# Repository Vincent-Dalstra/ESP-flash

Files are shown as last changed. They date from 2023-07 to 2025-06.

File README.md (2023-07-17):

# ESP-flash
A USB to UART Serial interface implementing a CH340C.

Designed primarily to program board with embedded ESP32 modules. USB-micro and USB-c for minimum I-have-the-wrong-cable

For compatibility with other programmers, it follow the the ESPFlash 1x6 Header convention. https://github.com/SuperHouse/ESPFlash
Big thanks to them for developing it and putting it out there.

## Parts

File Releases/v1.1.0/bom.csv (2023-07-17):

Comment | Designator | Footprint | LCSC
C14663 | C103 | Capacitor_SMD:C_0603_1608Metric | C14663
CH340C | U103 | Package_SO:SOIC-16_3.9x9.9mm_P1.27mm | C84681
USB_B_Micro | J101 | Connector_USB_custom:USB_Micro-B_Amphenol_10118194_Horizontal | C132563
GREEN | D102,D103 | LED_SMD:LED_0603_1608Metric | C72043
0ZCK0050FF2E (TLC-PSMD050) | F101 | Fuse:Fuse_0805_2012Metric_Pad1.15x1.40mm_HandSolder | C261942
10kΩ | R105,R106 | Resistor_SMD:R_0603_1608Metric | C25804
10k | R103,R104 | Resistor_SMD:R_0805_2012Metric | C17414
10nF | C104 | Capacitor_SMD:C_0603_1608Metric | C14663
4.7uF/6V | C102 | Capacitor_SMD:C_0805_2012Metric | C1779
USB_C_Receptacle_USB2.0 | J102 | Connector_USB:USB_C_Receptacle_HRO_TYPE-C-31-M-12 | C165948
SW_SPDT | SW101 | Button_Switch_SMD:SW_SPDT_CK-JS102011SAQN | C125040
MMDT3904 | Q101 | Package_TO_SOT_SMD:SOT-363_SC-70-6 | C83572
5.1k | R101,R102 | Resistor_SMD:R_0603_1608Metric | C23186
ESD5Z3.3T1G | D101 | Diode_SMD:D_SOD-523 | C61148
1uF/10V | C101 | Capacitor_SMD:C_0805_2012Metric | C28323
TLV75533PDBV | U102 | Package_TO_SOT_SMD:SOT-23-5 | C2937042
ESD PROTECTION | U101 | Package_TO_SOT_SMD:SOT-23-6 | C294963

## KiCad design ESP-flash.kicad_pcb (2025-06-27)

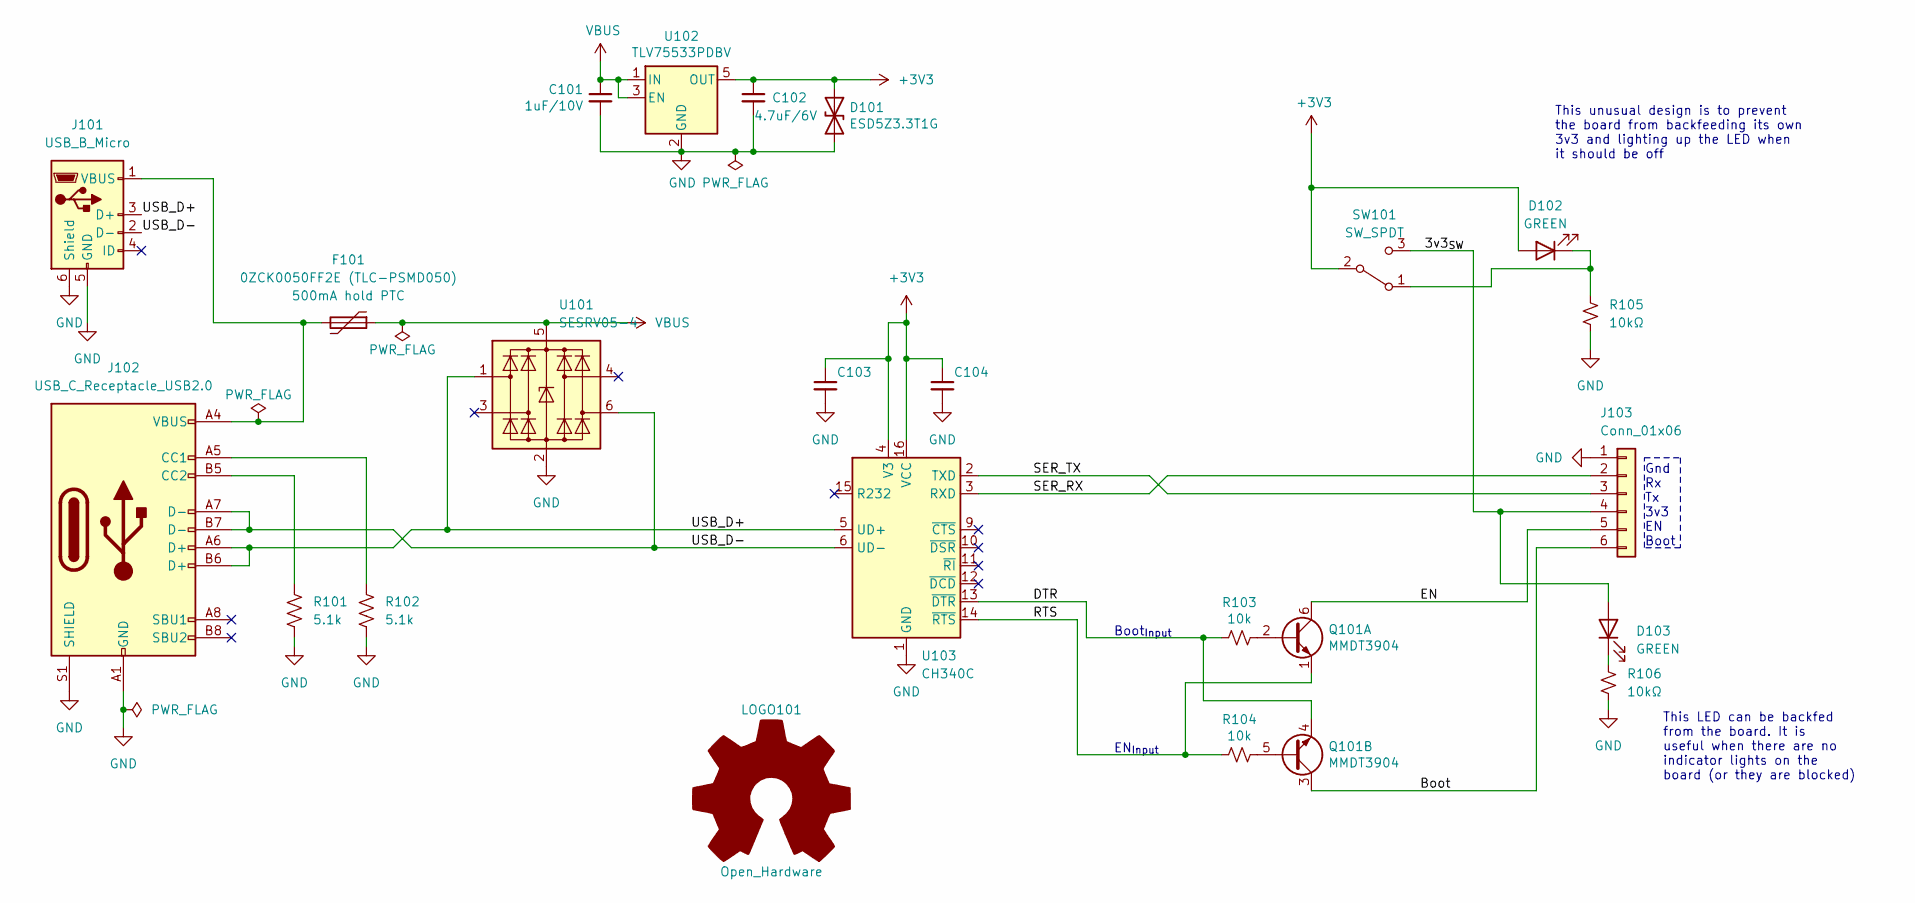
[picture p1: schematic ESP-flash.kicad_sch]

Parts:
C101: 1uF/10V; C_0805_2012Metric; LCSC C28323
C102: 4.7uF/6V; C_0805_2012Metric; LCSC C1779
C103: C14663; C_0603_1608Metric; LCSC C14663
C104: 10nF; C_0603_1608Metric; LCSC C14663
D101: ESD5Z3.3T1G; D_SOD-523; LCSC C61148
D102, D103: GREEN; LED_0603_1608Metric; LCSC C779453
F101: 0ZCK0050FF2E (TLC-PSMD050); Fuse_0805_2012Metric_Pad1.15x1.40mm_HandSolder; LCSC C516070
J101: USB_B_Micro; USB_Micro-B_Amphenol_10118194_Horizontal; LCSC C132563
J102: USB_C_Receptacle_USB2.0; USB_C_Receptacle_HRO_TYPE-C-31-M-12; LCSC C165948
J103: Conn_01x06; PinHeader_1x06_P2.54mm_Horizontal; LCSC C40877
LOGO101: Open_Hardware; OSHW-Logo2_7.3x6mm_SilkScreen
Q101: MMDT3904; SOT-363_SC-70-6; LCSC C83572
R101, R102: 5.1k; R_0603_1608Metric; LCSC C23186
R103, R104: 10k; R_0805_2012Metric; LCSC C17414
R105, R106: 10kΩ; R_0603_1608Metric; LCSC C25804
SW101: SW_SPDT; SW_SPDT_PCM12; LCSC C221841
U101: SESRV05-4; SOT-23-6; LCSC C294963
U102: TLV75533PDBV; SOT-23-5; LCSC C2937042
U103: CH340C; SOIC-16_3.9x9.9mm_P1.27mm; LCSC C84681

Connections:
+3V3: C102.1, C103.1, C104.1, D101.1 (A1), D102.2 (A), SW101.2 (B), U102.5 (OUT), U103.4 (V3), U103.16 (VCC)
/3v3_{SW}: D103.2 (A), J103.4, SW101.3 (C)
/Boot: J103.6, Q101.3 (C2)
/DTR: Q101.4 (E2), R103.2, U103.13 (~DTR)
/EN: J103.5, Q101.6 (C1)
/RTS: Q101.1 (E1), R104.2, U103.14 (~RTS)
/SER_RX: J103.2, U103.3 (RXD)
/SER_TX: J103.3, U103.2 (TXD)
/USB_D+: J101.3 (D+), J102.A6 (D+), J102.B6 (D+), U101.1 (I/O1), U103.5 (UD+)
/USB_D-: J101.2 (D-), J102.A7 (D-), J102.B7 (D-), U101.6 (I/O4), U103.6 (UD-)
GND: C101.2, C102.2, C103.2, C104.2, D101.2 (A2), J101.5 (GND), J101.6 (Shield), J102.A1 (GND), J102.A12 (GND), J102.B1 (GND), J102.B12 (GND), J102.S1 (SHIELD), J103.1, R101.1, R102.1, R105.2, R106.2, U101.2 (GND), U102.2 (GND), U103.1 (GND)
unnamed: D102.1 (K), R105.1, SW101.1 (A)
unnamed: D103.1 (K), R106.1
unnamed: F101.2, J101.1 (VBUS), J102.A4 (VBUS), J102.A9 (VBUS), J102.B4 (VBUS), J102.B9 (VBUS)
unnamed: J102.A5 (CC1), R102.2
unnamed: J102.B5 (CC2), R101.2
unnamed: Q101.2 (B1), R103.1
unnamed: Q101.5 (B2), R104.1
VBUS: C101.1, F101.1, U101.5 (VBUS), U102.1 (IN), U102.3 (EN)

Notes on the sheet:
Gnd Rx Tx 3v3 EN Boot
Boot_{Input}
EN_{Input}
This unusual design is to prevent the board from backfeeding its own 3v3 and lighting up the LED when it should be off
This LED can be backfed from the board. It is useful when there are no indicator lights on the board (or they are blocked)

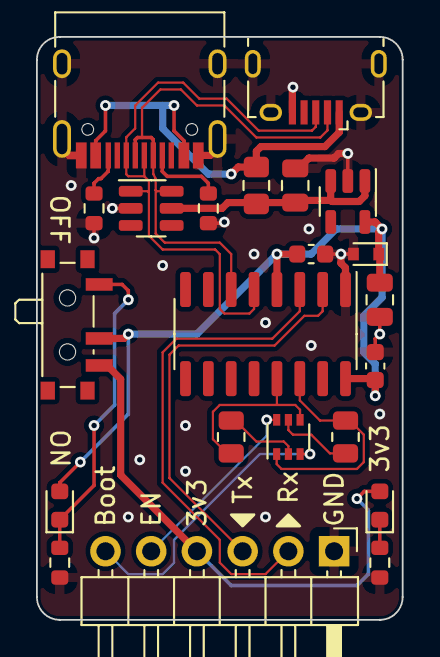
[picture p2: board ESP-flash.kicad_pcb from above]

Board: 2 copper layers, 20.3 x 32.4 mm, 23 parts (1 on the bottom side), 19 nets.

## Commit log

2022-12-09 Created from template, schematic complete
    [EFP-flash.kicad_pcb, EFP-flash.kicad_sch]
2022-12-20 PCB complete
    [EFP-flash.kicad_pcb, EFP-flash.kicad_sch]
2022-12-23 Sent to board fab v1.0.0
    [bom.csv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]
2023-01-03 Sent to board fab v1.0.1, replaces previous
    Changes:
    - USB diodes out of stock; different manufacturer had their stock.
    - SPDT switch out of stock, replaced with a different switch that
    thankfully also had a footprint in KiCAD
    - Made the board slightly wider to accomodate the switch.
    [EFP-flash.kicad_pcb, EFP-flash.kicad_sch, bom.csv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]
2023-02-15 Bugfix: PWR LED backfed from board
    Power LED would light up when board was using its own 3v3 Power, even
    though the switch was in the off position.
    Found a clever solution to fix this, by changing two short traces.
    [EFP-flash.kicad_pcb, EFP-flash.kicad_sch]
2023-05-19 Added Silskcreen gnd-pin indicator
    To match up with the arrows on PCB's that use this programmer.
    [EFP-flash.kicad_pcb]
2023-06-30 Changed from right-angled to straight shape
    For a lot of boards, the sideways design means the cable tends to get in
    the way of things, especially cases. A straight-through format that can
    be plugged in vertically would do much better.
    [EFP-flash.kicad_pcb]
2023-07-01 Add 2nd indicator LED
    - The first one is linked to the switch, and indicates when the switch
    is closed, linking the 3v3 nets together.
    - The second one is linked directly to the 3v3 pin on the programmer. It
    will also turn on when the target board has its own power source.
    [EFP-flash.kicad_pcb, EFP-flash.kicad_sch]
2023-07-13 Convert to 7.0 format, fix DRC errors
    Opened and saved with KiCAD 7.0
    Fix a few unconnected components. Adjusted DRC violation severities to
    ignore silkscreen over board edge (because they're usually on purpose
    and don't help track down errors).
    [EFP-flash.kicad_pcb, EFP-flash.kicad_sch]
2023-09-26 squash! Sent to baord fab [1.1.0]
    Made the ESD protection IC a library symbol.
    [EFP-flash.kicad_sch]
2025-06-26 Bump version number, fix name, update makefile and .gitignore
    [EFP-flash.kicad_pcb, EFP-flash.kicad_sch, ESP-flash.kicad_pcb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]
2025-06-27 Substitute out-of-stock components
    Unsurprising considering how long ago this was last ordered, some of the
    components were no longer stocked.
    - Green LED (already had a replacement, in other PCB designs)
    - Polyfuse (easily found another one on JLCPCB)
    - The SPDT switch (couldn't find an exact replacement, and ended up
    using another type with a already-available footprint).
    [ESP-flash.kicad_pcb, ESP-flash.kicad_sch]
